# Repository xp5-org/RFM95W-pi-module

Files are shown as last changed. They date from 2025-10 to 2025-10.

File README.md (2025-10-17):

# RFM95W-pi-module
PCB to connect RFM95W module to ras pi header

have not tested it yet, need to verify things are wired correctly and pinouts are correct

I set this up to be buildable on a single-layer routed or etched (home made) pcb . 

it relies upon jumper bodge wires to complete some of the wiring, otherwise this would be better served by at least 2 layers or 4 layers board.

ras pi zero has two SPI channels, which can allow up to two simutaenous radios/modems in use. 

<br>
<br>

## single radio layout ##


<br>
<br>

## dual radio layout ##


<br>
<br>

# converting kicad gerbers to G-code for CNC
http://flatcam.org/download

need to generate the isolation path (mill the PCB) and then generate the drill instructions (through-holes and vias drills) separately



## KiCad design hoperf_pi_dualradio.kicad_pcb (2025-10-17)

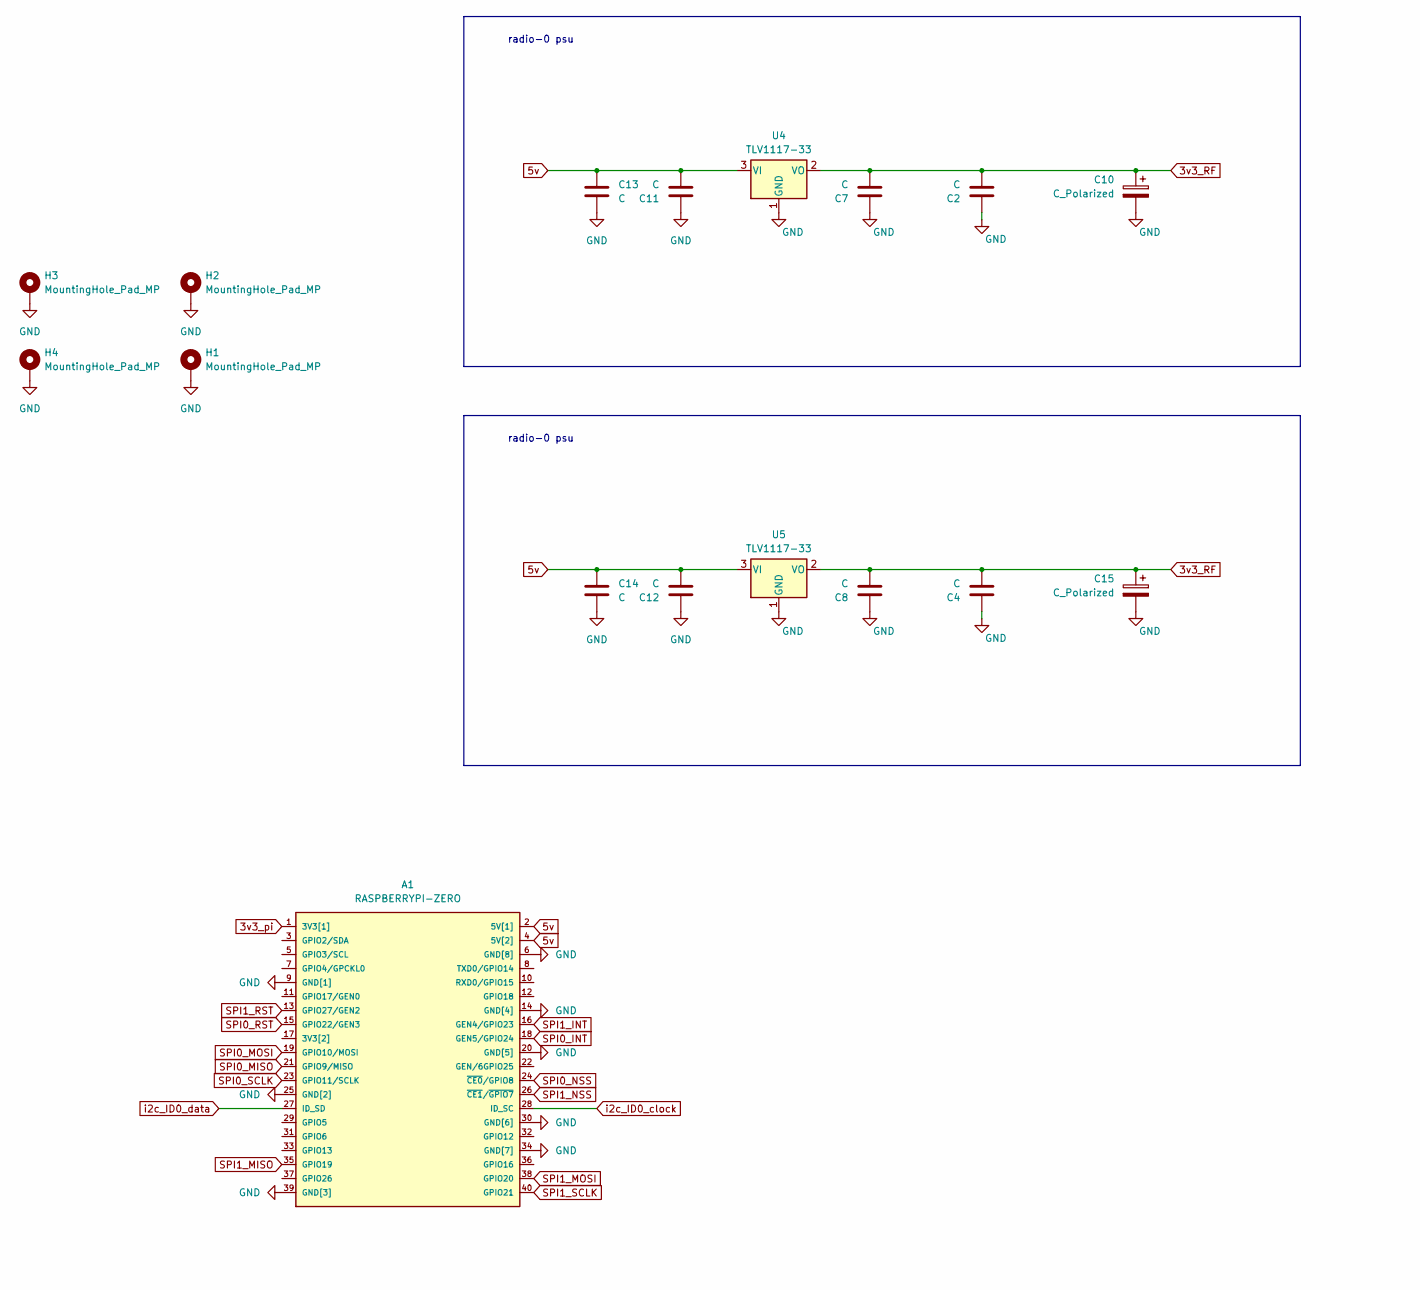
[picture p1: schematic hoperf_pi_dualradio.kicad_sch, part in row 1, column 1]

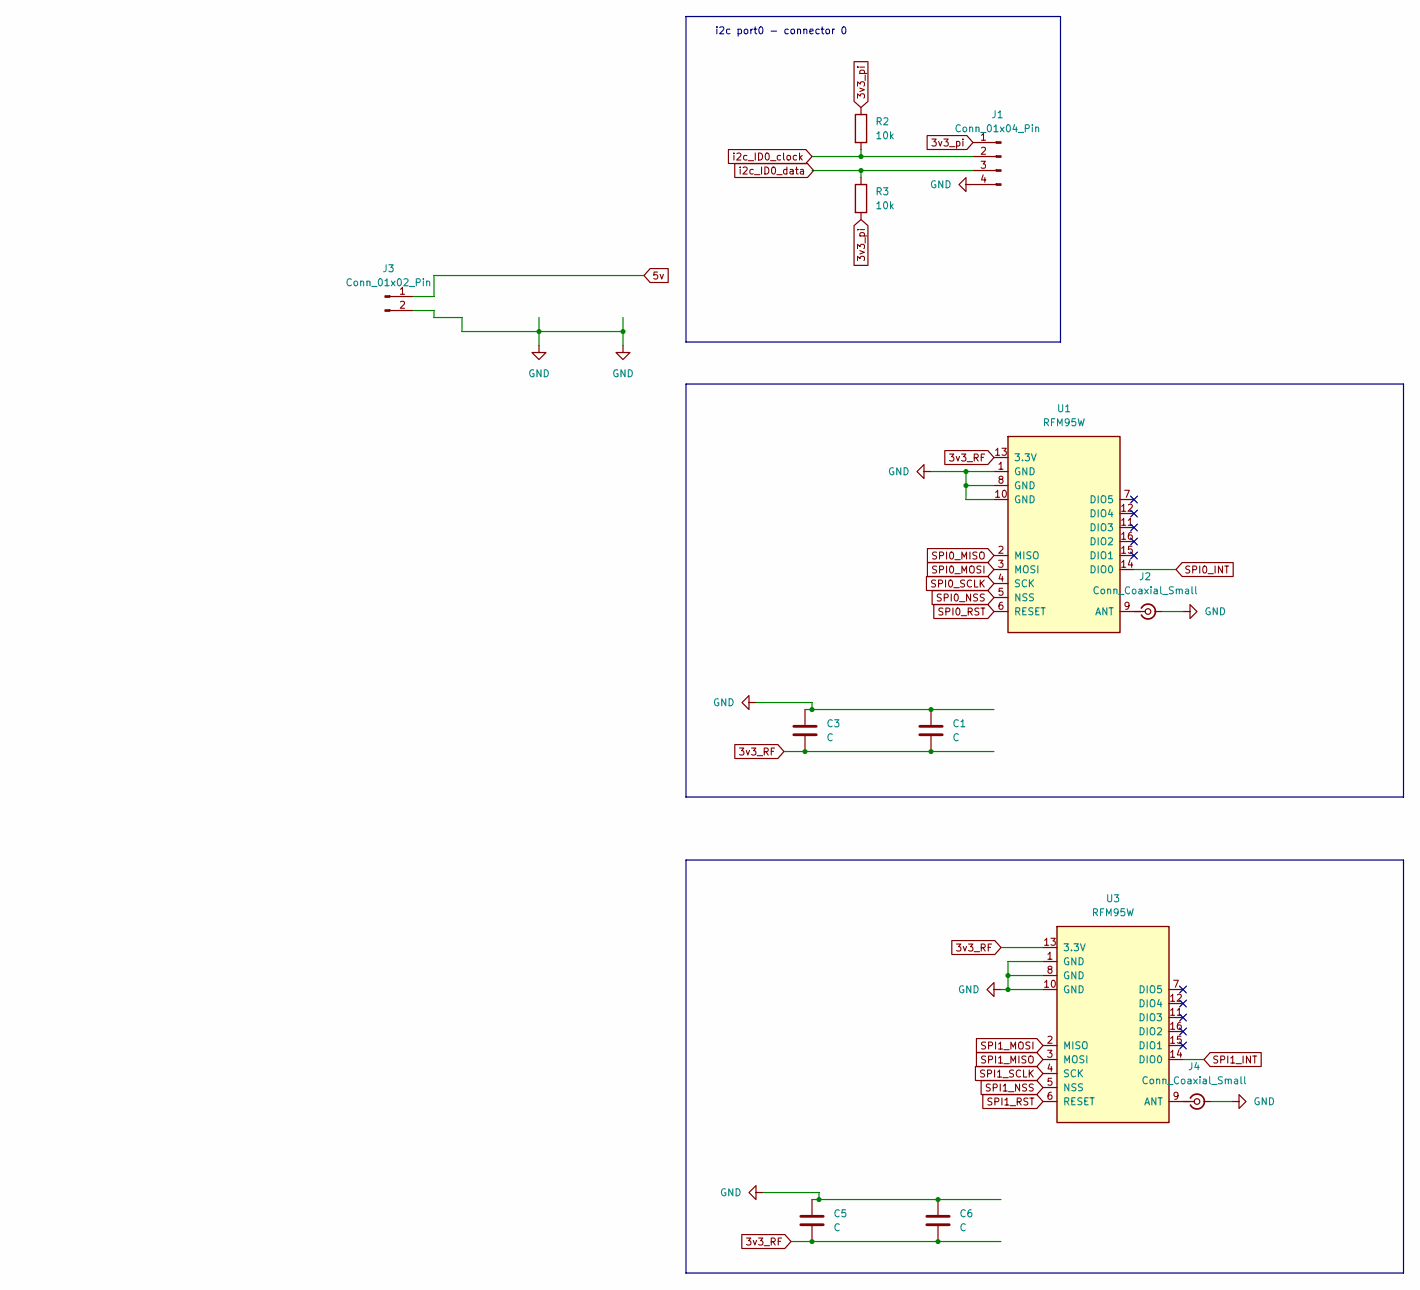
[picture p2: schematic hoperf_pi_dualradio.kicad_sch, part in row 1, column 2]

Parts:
A1: RASPBERRYPI-ZERO; Raspberry_Pi_Zero_Socketed_THT_FaceDown_MountingHoles
C1, C2, C3, C4, C5, C6, C7, C8, C11, C12, C13, C14: C; C_1206_3216Metric
C10, C15: C_Polarized; CP_EIA-7343-43_Kemet-X
H1, H2, H3, H4: MountingHole_Pad_MP; MountingHole_2.5mm_Pad
J1: Conn_01x04_Pin; Molex_PicoBlade_53048-0410_1x04_P1.25mm_Horizontal
J2, J4: Conn_Coaxial_Small; SMA_Amphenol_132289_EdgeMount
J3: Conn_01x02_Pin; PinHeader_1x02_P2.54mm_Horizontal
R2, R3: 10k; R_0603_1608Metric
U1, U3: RFM95W; my_RFM95W
U4, U5: TLV1117-33; SOT-223-3_TabPin2

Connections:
3v3_RF: C1.2, C2.2, C3.2, C4.2, C5.2, C6.2, C7.2, C8.2, C10.1, C15.1, U1.13 (3.3V), U3.13 (3.3V), U4.2 (VO), U5.2 (VO)
3v3_pi: A1.1 (3V3[1]), J1.1, R2.1, R3.2
5v: A1.2 (5V[1]), A1.4 (5V[2]), C11.2, C12.2, C13.1, C14.1, J3.1, U4.3 (VI), U5.3 (VI)
GND: A1.6 (GND[8]), A1.9 (GND[1]), A1.14 (GND[4]), A1.20 (GND[5]), A1.25 (GND[2]), A1.30 (GND[6]), A1.34 (GND[7]), A1.39 (GND[3]), C1.1, C2.1, C3.1, C4.1, C5.1, C6.1, C7.1, C8.1, C10.2, C11.1, C12.1, C13.2, C14.2, C15.2, H1.MP, H2.MP, H3.MP, H4.MP, J1.4, J2.2 (Ext), J3.2, J4.2 (Ext), U1.1 (GND), U1.8 (GND), U1.10 (GND), U3.1 (GND), U3.8 (GND), U3.10 (GND), U4.1 (GND), U5.1 (GND)
unnamed: J2.1 (In), U1.9 (ANT)
unnamed: J4.1 (In), U3.9 (ANT)
SPI0_INT: A1.18 (GEN5/GPIO24), U1.14 (DIO0)
SPI0_MISO: A1.21 (GPIO9/MISO), U1.2 (MISO)
SPI0_MOSI: A1.19 (GPIO10/MOSI), U1.3 (MOSI)
SPI0_NSS: A1.24 (~CE0/GPIO8), U1.5 (NSS)
SPI0_RST: A1.15 (GPIO22/GEN3), U1.6 (RESET)
SPI0_SCLK: A1.23 (GPIO11/SCLK), U1.4 (SCK)
SPI1_INT: A1.16 (GEN4/GPIO23), U3.14 (DIO0)
SPI1_MISO: A1.35 (GPIO19), U3.3 (MOSI)
SPI1_MOSI: A1.38 (GPIO20), U3.2 (MISO)
SPI1_NSS: A1.26 (~CE1/~GPIO7), U3.5 (NSS)
SPI1_RST: A1.13 (GPIO27/GEN2), U3.6 (RESET)
SPI1_SCLK: A1.40 (GPIO21), U3.4 (SCK)
i2c_ID0_clock: A1.28 (ID_SC), J1.2, R2.2
i2c_ID0_data: A1.27 (ID_SD), J1.3, R3.1

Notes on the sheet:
radio-0 psu
i2c port0 - connector 0

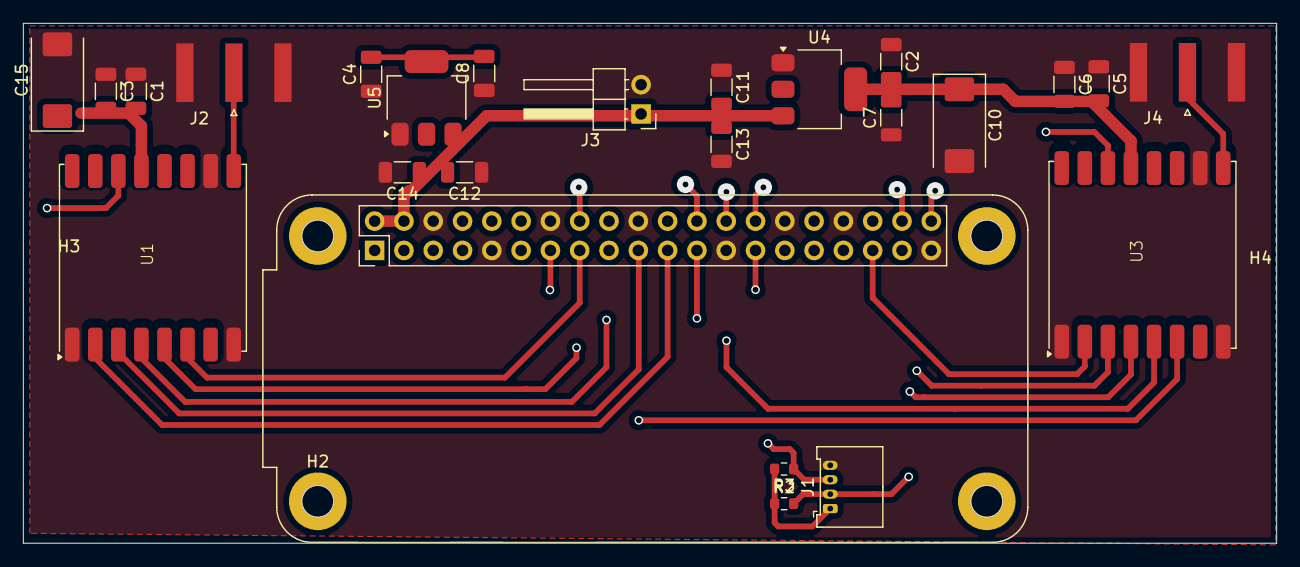
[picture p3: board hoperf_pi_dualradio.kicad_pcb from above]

Board: 2 copper layers, 108.7 x 45.1 mm, 29 parts (0 on the bottom side), 20 nets.

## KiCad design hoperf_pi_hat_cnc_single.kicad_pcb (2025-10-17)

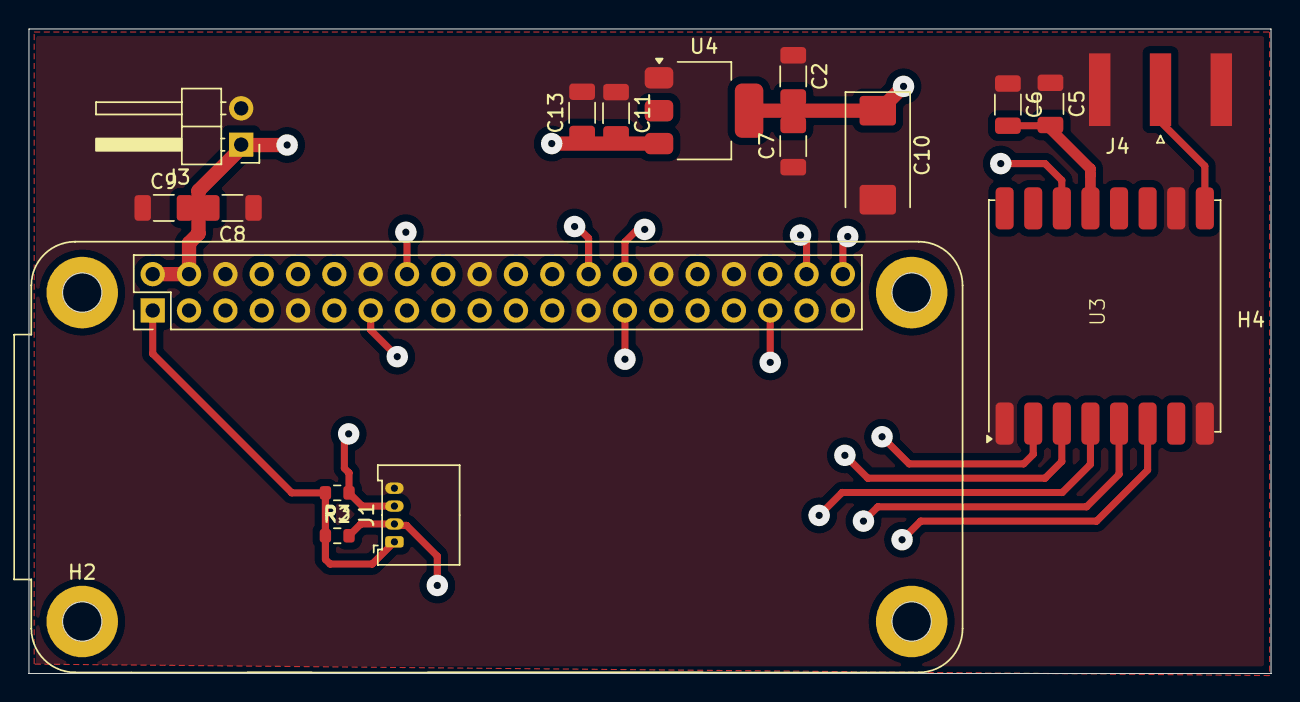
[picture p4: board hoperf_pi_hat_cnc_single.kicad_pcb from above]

Board: 2 copper layers, 86.9 x 45.1 mm, 21 parts (0 on the bottom side), 13 nets.

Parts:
A1: RASPBERRYPI-ZERO; Raspberry_Pi_Zero_Socketed_THT_FaceDown_MountingHoles
C2, C5, C6, C7, C8, C9, C11, C13: C; C_1206_3216Metric
C10: C_Polarized; CP_EIA-7343-43_Kemet-X
H1, H2, H3, H4: MountingHole_Pad_MP; MountingHole_2.5mm_Pad
J1: Conn_01x04_Pin; Molex_PicoBlade_53048-0410_1x04_P1.25mm_Horizontal
J3: Conn_01x02_Pin; PinHeader_1x02_P2.54mm_Horizontal
J4: Conn_Coaxial_Small; SMA_Amphenol_132289_EdgeMount
R2, R3: 10k; R_0603_1608Metric
U3: RFM95W; my_RFM95W
U4: TLV1117-33; SOT-223-3_TabPin2

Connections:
3v3_RF: C2.2, C5.2, C6.2, C7.2, C10.1, U3.13 (3.3V), U4.2 (VO)
3v3_pi: A1.1 (3V3[1]), J1.1, R2.1, R3.2
5v: A1.2 (5V[1]), A1.4 (5V[2]), C8.2, C9.2, C11.2, C13.1, J3.1, U4.3 (VI)
GND: A1.6 (GND[8]), A1.9 (GND[1]), A1.14 (GND[4]), A1.20 (GND[5]), A1.25 (GND[2]), A1.30 (GND[6]), A1.34 (GND[7]), A1.39 (GND[3]), C2.1, C5.1, C6.1, C7.1, C8.1, C9.1, C10.2, C11.1, C13.2, J1.4, J3.2, J4.2 (Ext), U3.1 (GND), U3.8 (GND), U3.10 (GND), U4.1 (GND)
unnamed: J4.1 (In), U3.9 (ANT)
SPI0_INT: A1.18 (GEN5/GPIO24), U3.14 (DIO0)
SPI0_MISO: A1.21 (GPIO9/MISO), U3.2 (MISO)
SPI0_MOSI: A1.19 (GPIO10/MOSI), U3.3 (MOSI)
SPI0_NSS: A1.24 (~CE0/GPIO8), U3.5 (NSS)
SPI0_RST: A1.15 (GPIO22/GEN3), U3.6 (RESET)
SPI0_SCLK: A1.23 (GPIO11/SCLK), U3.4 (SCK)
i2c_ID0_clock: A1.28 (ID_SC), J1.2, R2.2
i2c_ID0_data: A1.27 (ID_SD), J1.3, R3.1

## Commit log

2025-10-17 added project files
    [hoperf_pi_dualradio.kicad_pcb, hoperf_pi_dualradio.kicad_sch, hoperf_pi_hat_cnc_single.kicad_pcb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]
2025-10-17 Update README.md
    added screenshots from kicad
